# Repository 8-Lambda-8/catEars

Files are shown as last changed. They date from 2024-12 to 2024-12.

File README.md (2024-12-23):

# A CatEar headband with LEDs!

[Interactive BOM](https://htmlpreview.github.io/?https://raw.githubusercontent.com/8-Lambda-8/catEars/master/bom/ibom.html)

## Some components are only needed on one of each Pair of ears:
* U1 - ESP01
* U2 - AMS1117-3.3 (3.3V voltage regulator for the ESP)
* C11, C12 - 22uF (Capacitors for voltage regualtor)
* R1, R2, R3 - 10kΩ Resistors (Pull up/donw Resistors for booting the ESP)
* R4 - 120Ω Resistor (signal output from ESP to th WS2812) 

(3D print the CatEars with transparent materials)

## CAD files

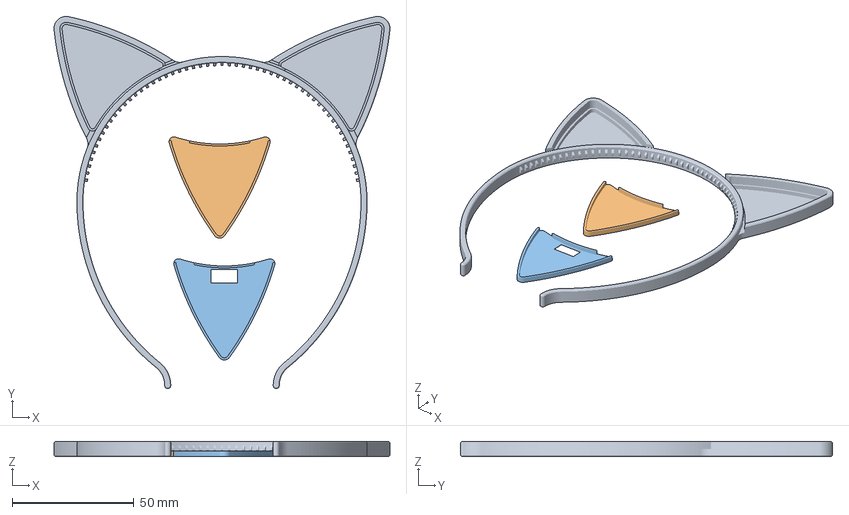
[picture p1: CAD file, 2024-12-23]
CatEars.3mf
137.8 x 152.6 x 6.00 mm
CatEars.stl_1
CatEars.stl_2
CatEars.stl_3

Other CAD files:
CatEars.stl

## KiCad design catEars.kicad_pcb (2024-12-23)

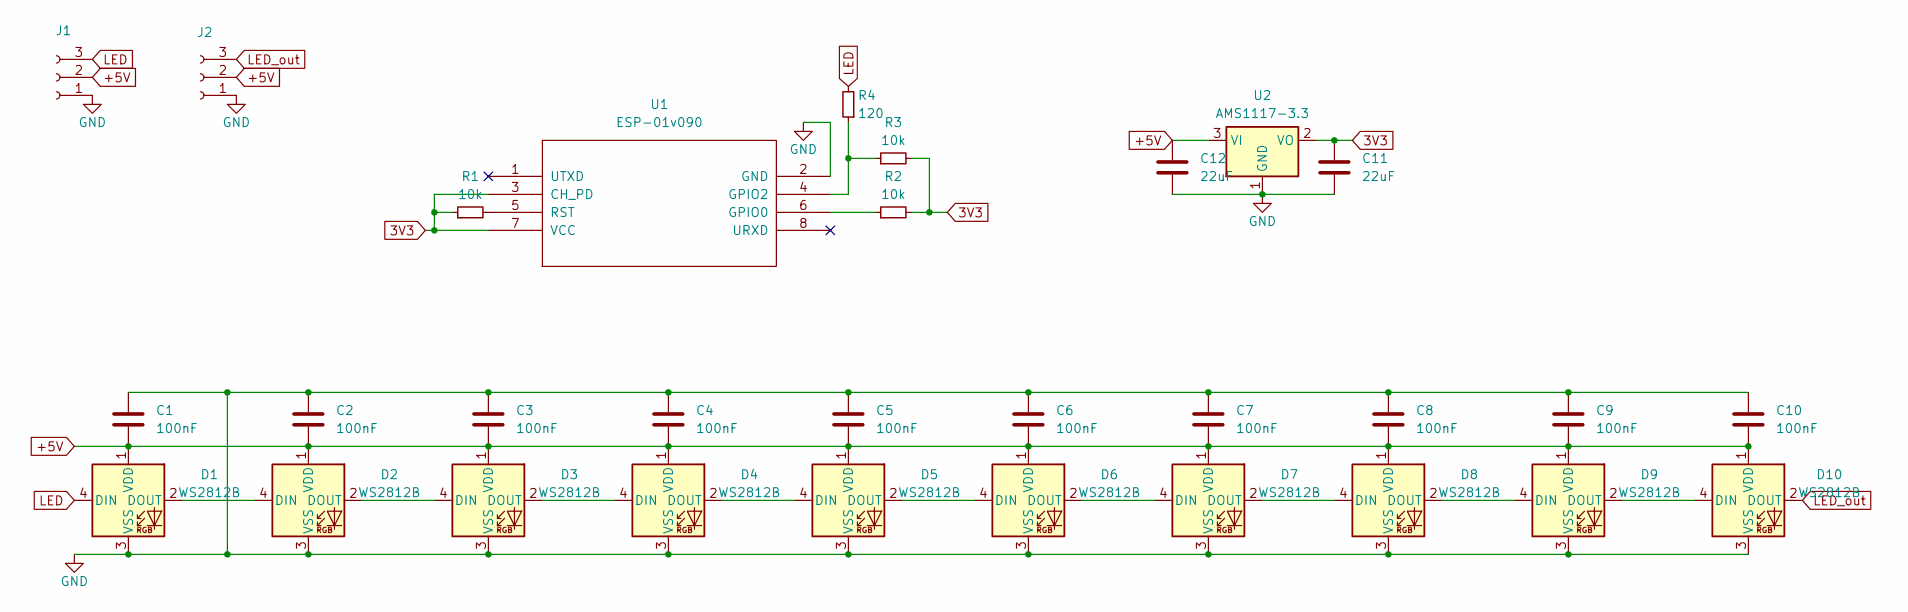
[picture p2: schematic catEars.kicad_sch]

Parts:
C1, C2, C3, C4, C5, C6, C7, C8, C9, C10: 100nF; C_0805_2012Metric_Pad1.18x1.45mm_HandSolder
C11, C12: 22uF; C_0805_2012Metric_Pad1.18x1.45mm_HandSolder
D1, D2, D3, D4, D5, D6, D7, D8, D9, D10: WS2812B; LED_WS2812B_PLCC4_5.0x5.0mm_P3.2mm
J1, J2: PinHeader_1x03_P2.54mm_Vertical
R1, R2, R3: 10k; R_0805_2012Metric_Pad1.20x1.40mm_HandSolder
R4: 120; R_0805_2012Metric_Pad1.20x1.40mm_HandSolder
U1: ESP-01v090; ESP-01
U2: AMS1117-3.3; SOT-223-3_TabPin2

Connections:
3V3: C11.1, R1.1, R2.2, R3.2, U1.3 (CH_PD), U1.7 (VCC), U2.2 (VO); also elsewhere on the board
+5V: C1.2, C2.2, C3.2, C4.2, C5.2, C6.2, C7.2, C8.2, C9.2, C10.2, C12.1, D1.1 (VDD), D2.1 (VDD), D3.1 (VDD), D4.1 (VDD), D5.1 (VDD), D6.1 (VDD), D7.1 (VDD), D8.1 (VDD), D9.1 (VDD), D10.1 (VDD), J1.2, J2.2, U2.3 (VI)
GND: C1.1, C2.1, C3.1, C4.1, C5.1, C6.1, C7.1, C8.1, C9.1, C10.1, C11.2, C12.2, D1.3 (VSS), D2.3 (VSS), D3.3 (VSS), D4.3 (VSS), D5.3 (VSS), D6.3 (VSS), D7.3 (VSS), D8.3 (VSS), D9.3 (VSS), D10.3 (VSS), J1.1, J2.1, U1.2 (GND), U2.1 (GND); also elsewhere on the board
LED: D1.4 (DIN), J1.3, R4.2
LED_out: D10.2 (DOUT), J2.3
unnamed: D1.2 (DOUT), D2.4 (DIN)
unnamed: D2.2 (DOUT), D3.4 (DIN)
unnamed: D3.2 (DOUT), D4.4 (DIN)
unnamed: D4.2 (DOUT), D5.4 (DIN)
unnamed: D5.2 (DOUT), D6.4 (DIN)
unnamed: D6.2 (DOUT), D7.4 (DIN)
unnamed: D7.2 (DOUT), D8.4 (DIN)
unnamed: D8.2 (DOUT), D9.4 (DIN)
unnamed: D9.2 (DOUT), D10.4 (DIN)
unnamed 14: R2.1, U1.6 (GPIO0); also elsewhere on the board
unnamed 15: R3.1, R4.1, U1.4 (GPIO2); also elsewhere on the board
unnamed 16: R1.2, U1.5 (RST); also elsewhere on the board

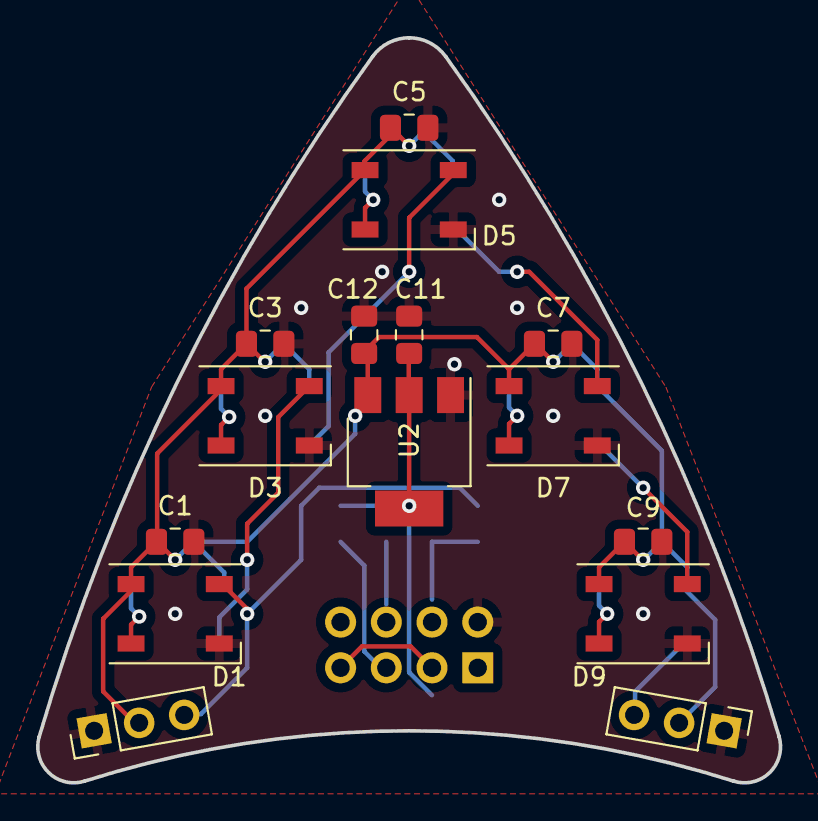
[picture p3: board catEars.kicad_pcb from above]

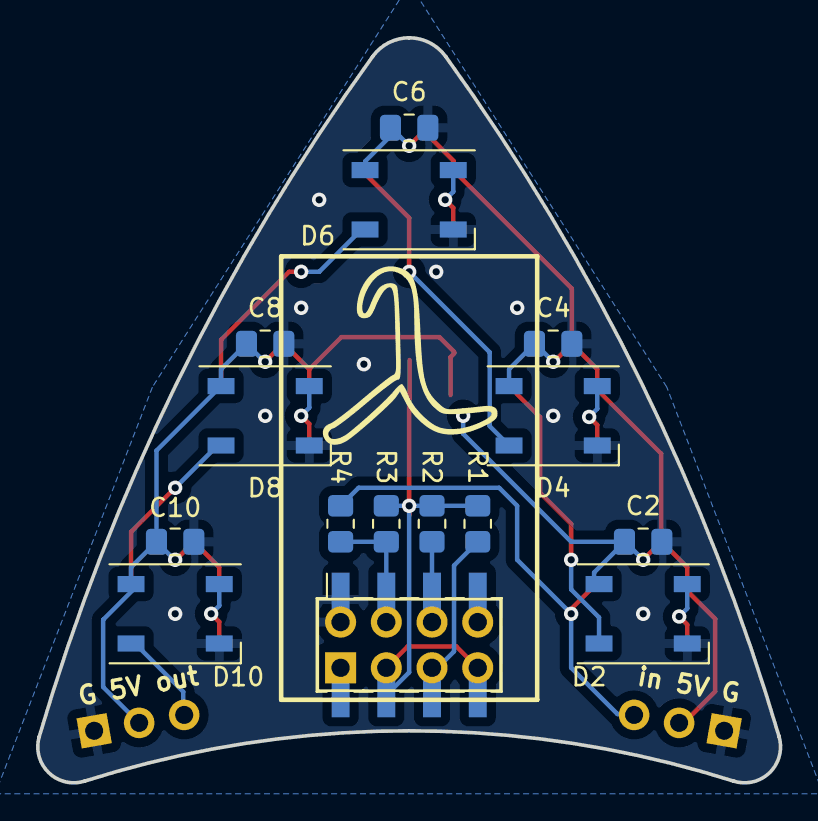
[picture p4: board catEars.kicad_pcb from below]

Board: 2 copper layers, 41.3 x 41.4 mm, 31 parts (16 on the bottom side), 17 nets.

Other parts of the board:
U1_: PinSocket_2x04_P2.54mm_Vertical_SMD

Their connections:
3V3: U1_.4, U1_.8; also elsewhere on the board
GND: U1_.1; also elsewhere on the board
unnamed 14: U1_.5; also elsewhere on the board
unnamed 15: U1_.3; also elsewhere on the board
unnamed 16: U1_.6; also elsewhere on the board

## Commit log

2024-01-04 fixed WS2812 VSS VDD
    [catEars.kicad_pcb, catEars.kicad_sch]
2024-01-07 some optimisations
    [catEars.kicad_pcb, catEars.kicad_sch]
2024-01-07 moved PCB to origin
    [catEars.kicad_pcb]
2024-01-20 added gerber folder to gitignore
    [catEars.kicad_pcb]
2024-01-23 changed led order from left to right
    [catEars.kicad_pcb]
2024-01-23 changed R12 value
    [catEars.kicad_sch]
2024-01-23 pcb update
    [catEars.kicad_pcb]
2024-01-23 new positioning for components
    [catEars.kicad_pcb]
2024-02-10 added 2 leds in schematic
    [catEars.kicad_sch]
2024-02-10 added 2 leds and smd ESP Socket to PCB
    [catEars.kicad_pcb]
2024-02-10 updated board outlines
    [catEars.kicad_pcb]
2024-02-11 created pannel
    [catEars.kicad_pcb, catEars_panelized.kicad_pcb]
2024-03-20 added 3D Files
    [CatEars.3mf, CatEars.stl]
2024-03-20 removed KiKit footprints from iBOM
2024-12-23 improved stl file
    [CatEars.stl]
2024-12-23 updated .3mf printfile
    [CatEars.3mf]
2024-12-23 changed C11 value
    [catEars.kicad_pcb, catEars.kicad_sch, catEars_panelized.kicad_pcb]
